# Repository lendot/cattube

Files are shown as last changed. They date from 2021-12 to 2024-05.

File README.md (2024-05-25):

# CatTube
### On-demand Video Entertainment For Cats

## 1. Intro
Cat walks up to screen, videos start playing. Cat walks away from screen,
videos stop playing. That's the gist of CatTube. A Raspberry Pi with an
ultrasonic distance sensor attached is given the CatTube software and
whatever videos a particular cat likes to watch, and when the sensor
detects they're within range, the videos will start playing until they 
leave.

We've had this system running for about 6 years in our living room and
two of our cats love it and use it multiple times a day. Not only that,
they grasped it intuitively right from the beginning and there really wasn't
any training required.

## 2. Hardware

- Raspberry Pi 3 or 4 (5 should work too, but I haven't tested yet)
- HDMI-capable monitor/TV
- US-100 ultrasonic sensor. These can be found at several electronics
supply places, including [Adafruit](https://www.adafruit.com/product/4019).
- Wires to connect the sensor to the Pi. F-F jumper wires are simplest.
If you 3D print the supplied enclosure design, 3" jumpers work best.

### 2.1. Hookup

Make the following connections between the US-100 and the Raspberry Pi:
| US-100 | Raspberry Pi |
| --- | --- |
| VCC | Pin 1 (+3V3) |
| Trig/Tx | Pin 8 (TXD0 UART, aka GPIO14) |
| Echo/Rx | Pin 10 (RXD0 UART, aka GPIO15) |
| GND (1) | Pin 6 (GND) |
| GND (2) | Pin 9 (GND) |

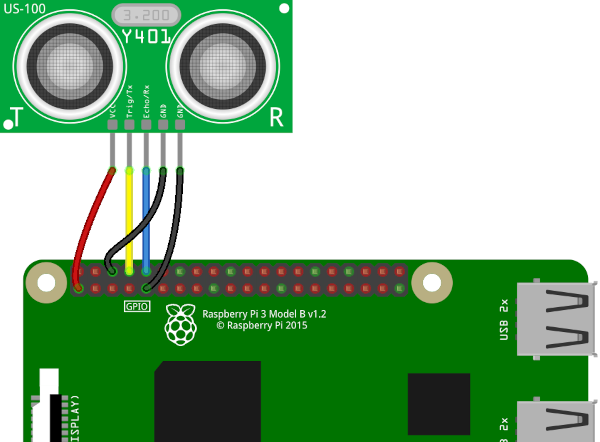
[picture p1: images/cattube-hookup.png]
wiring connections between Raspberry Pi and US-100


I haven't gotten around to investigating why this sensor breaks out 2
grounds. There's continuity between them so one could probably get away
with hooking up just one, but I do both just to be on the safe side.

## 3. Enclosure and Sensor Positioning

At minimum, you'll need some way to hold the sensor in place somewhere
at cat-level. If you have access to a 3D printer, .stl files for a wall-mount
enclosure are included in [enclosure](enclosure).

Keep the immediate area around the sensor free of obstructions, both on the 
sides and above and below. If an item such as the bottom edge of a television,
the side of a shelf, or even the floor is too close to the sensor, that
can cause the video player to activate and remain on. 

One good setup that doesn't take up much space is to wall-mount a small
TV/monitor a few inches above the sensor (the bottom of ours is 3.5" above
the sensor). Then you just need to allocate a roughly 2' x 2' space in
front of that TV where your cats can watch their videos.

## 4. Software

### 4.1. Operating system

If not installed already, install [Raspberry Pi OS](https://www.raspberrypi.com/software/).
Use the default operating system option recommended for your hardware.

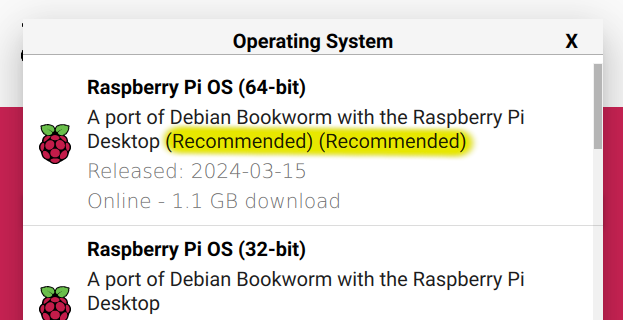
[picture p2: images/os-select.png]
Raspberry Pi OS installer Operating System dropdown sample highlighting the recommended option


NOTE: These instructions assume your Pi user is `pi`. If you set it to something else, you'll need to update all `/home/pi` references here and in `cattube.desktop` accordingly.

Make sure the Pi has internet access and has run its system updates before
continuing.

### 4.2. Python version

Open a terminal and run the following command to check your python version:
```
python --version
```
If the python version is 3.9.x or lower, proceed to the next section. If your
system comes with python 3.10 or higher you'll need to get a lower version 
installed first as one of the package dependencies doesn't yet support these newer
versions. One way to do this is by installing [pyenv](https://github.com/pyenv/pyenv) 
and using it to build and install python 3.9.x.

Here are the bare-bones commands for doing that after installing pyenv;
depending on your system you may need to install other system packages in order
to successfully build python.

These commands will install the python build dependencies, make sure tcl and tk
are installed so tkinter GUI support gets built in, and build and install the
specified python version. 3.9.18 is used here as that's the most recent 
python 3.9 release for pyenv as of this writing; see the pyenv documentation
for info on updating and listing available versions.

```sh
sudo apt install libbz2-dev libncurses-dev libffi-dev libreadline-dev liblzma-dev liblzma-dev liblzma-dev tcl tk tcl-dev tk-dev
pyenv install 3.9.18
```

### 4.3. Software install

Open a terminal and run the following commands to download CatTube and set up its run environment:
```sh
git clone https://github.com/lendot/cattube.git
cd cattube
# run the following command ONLY if you installed pyenv above
pyenv local 3.9.18
# run all the rest of these commands
python -m venv venv
source venv/bin/activate
pip install -r requirements.txt
cp cattube.desktop ../Desktop
```

Open File Manager and go to `Edit` > `Preferences` > `General` and check
"Don't ask options on launch executable file". You can then close that
window and exit File Manager.

From the desktop menu go to `Preferences` > `Raspberry Pi Configuration`
and do the following:
1. Go to the `Display` tab and disable `Screen Blanking`
2. Go to the `Interfaces` tab and enable `Serial Port`
3. If there is a `Serial Console` option, disable it

Click Ok and select Yes when asked to reboot.

### 4.4. Configuration
The configuration file is in `/home/pi/cattube/config.yaml`. It can be edited
with any text editor. The following settings can be tweaked there:

| Setting | Default | Description |
| --- | --- | --- |
| video_dir | /home/pi/Videos | Location of videos to play |
| distance | 50 | Maximum distance (cm) at which sensor will activate | 
| play_clips | False | If False, videos are played in their entirety. If True, random shorter subsections are played at a time |
| clip_duration| 180 | If play_clips is True, the length of clips (in seconds) to play |
| idle_timeout | 15 | How many seconds to keep playing the active video after the cat leaves before going back into standby, 0 = play out entire video/clip | 
| sensor_device| /dev/ttyS0 | If you need the sensor to to use a different serial device, set it here |

To help figure out the right distance setting to use in your configuration
file, or to determine if there are any obstacles interfering with a proper
distance reading, you can open up a terminal window and do the following:

```sh
cd ~/cattube
source venv/bin/activate
python sensor_readout.py
```

This will bring up a window that continuously updates a display of the
sensor's distance reading. As with the configuration file, values are in
centimeters.

play_clips is useful if you have longer videos and don't want the cats to get
bored watching them all the way through. Clip durations betwen about 120s and
300s seem to work well for our cats.

idle_timeout is also good for long videos as it can make video playing stop a
few seconds after a cat leaves rather than continuing dozens more minutes
(or longer).

### 4.5. Adding Videos

No videos are provided with CatTube. By default, it looks for videos in
`/home/pi/Videos`. Currently only mp4 videos are supported. See the Tips
For Videos section below for more information.

You can download videos from a browser or other application on the Pi desktop,
or you can use, say, sftp from another machine (assuming SSH is enabled on
the Pi). If you upload videos from another machine while CatTube is running,
it'll automatically add them to its video pool without requiring a restart.

### 4.6. Running CatTube

Once the hardware is hooked up and you have at least one video in your videos
directory, you can run CatTube. Double-click the CatTube icon on the
desktop to launch it. Simply clicking the left mouse button will exit the
program. Otherwise, no keyboard or mouse is required for the program to
function.

If you want CatTube to automatically start whenever the system boots up,
open a terminal window and run the following commands:
```sh
mkdir ~/.config/autostart
cd ~/cattube
cp cattube.desktop ~/.config/autostart
```

### 4.7. Troubleshooting

CatTube keeps a log file in `/home/pi/cattube/cattube.log`. Check that first
if anything's amiss.

## 5. Tips For Videos
We've found that the best videos are ones filmed from a single, stationary
camera. If the camera is moving, or the video is cutting between multiple
cameras, it gets more confusing for the cats to track. Youtube and other
places have a lot of good single camera little-critters-in-the-woods videos
and the like that our cats take really well to.

I recommend trying a bunch of different types of videos to see what your cat
responds to. In addition to the nature videos ours also like videos of
animated critters and things like balls rolling around. They're even sometimes
interested in gameplay videos from stuff like Tetris or Centipede. One of our
cats absolutely loves Line Rider videos. A while back I put an OK Go video
on ours just for laughs and months on our cats still really like watching
it. You never know what might grab their attention.

CatTube uses vlc to play the videos. The version that comes with
Raspberry Pi OS isn't compiled with hardware acceleration enabled, which limits
performance. A Pi 3 can handle standard 1K HD <= 30 FPS fine, but 4k or higher
frame rates give it trouble. Pi 4 is more forgiving. If a video is playing really
slowly, or is giving a black screen, you may need to decrease the resolution
and/or frame rate.

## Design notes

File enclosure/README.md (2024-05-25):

# Enclosure Files

Here are files for Pi 3 and 4 enclosures should you wish to 3D print
one. The ultrasonic sensor mounts on the underside of the cover through
the cat's eyes using the 2 standoffs and 2 M2x8 screws. The Pi mounts
to the body with 4 M2.5x8 screws. The body mounts to the wall via 2 #6
or #8 screws/anchors.

If you're having trouble getting the Pi in place, try rotating it into
position as shown here:

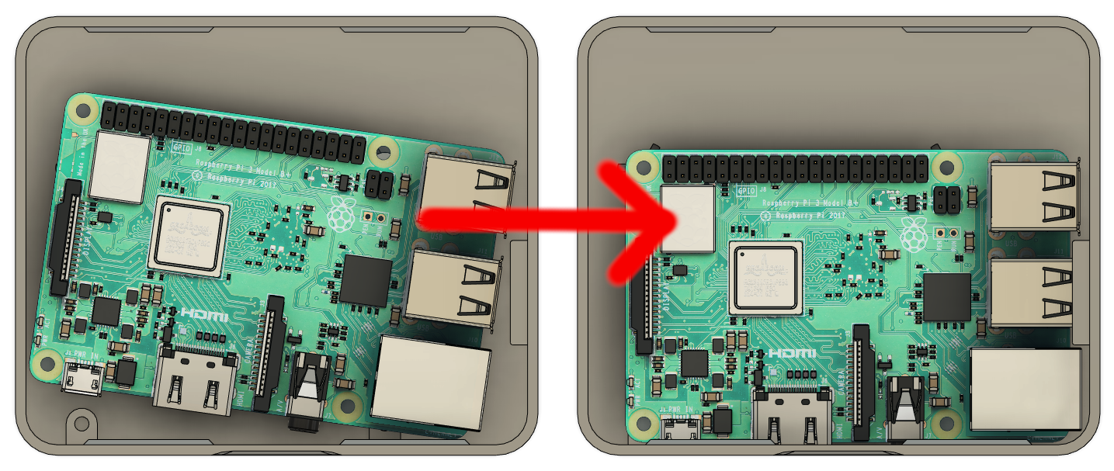
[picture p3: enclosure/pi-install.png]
installing Pi 3 in enclosure


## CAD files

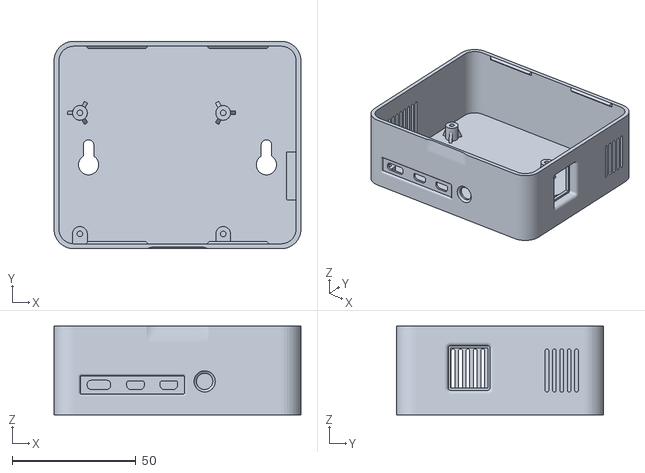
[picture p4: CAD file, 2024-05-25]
enclosure/body-pi4.stl
100.0 x 84.0 x 36.0

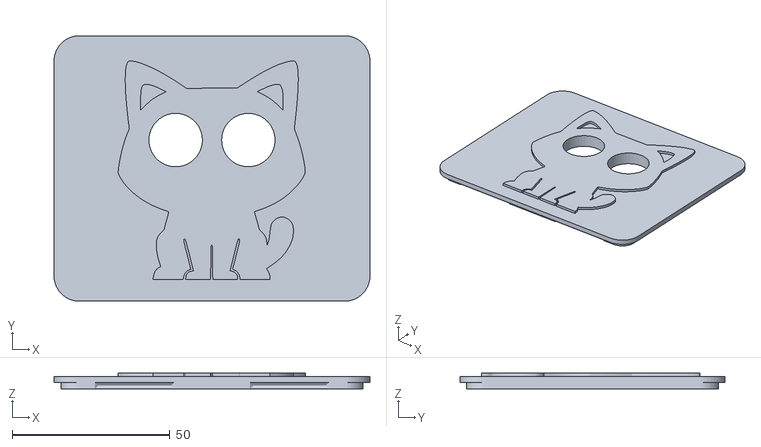
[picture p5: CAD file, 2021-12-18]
enclosure/cover.stl
100.0 x 84.0 x 5.00

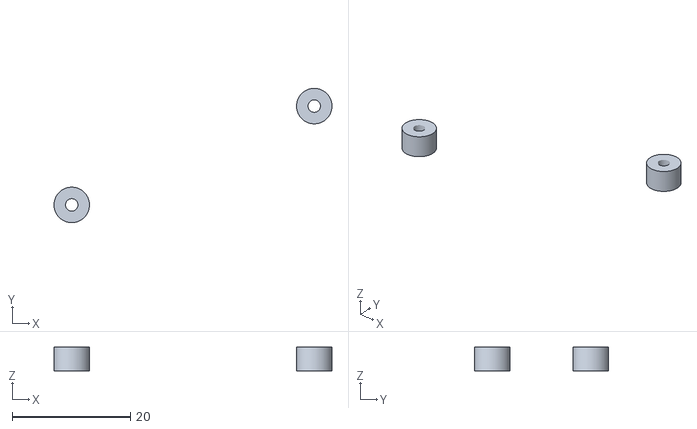
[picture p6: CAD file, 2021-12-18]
enclosure/standoffs.stl
47.0 x 22.7 x 4.00

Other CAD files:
enclosure/body-pi3.stl

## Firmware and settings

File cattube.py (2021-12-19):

import logging
import config
import videos
import distance_sensor
import tkinter as tk
import vlc
import random
import time

LOG_FILE = "cattube.log"

# number of seconds to wait after inactivity before stopping the running video
# 0 = don't time out 
DEFAULT_IDLE_TIMEOUT = 15

class View(tk.Frame):
    """ Top-level application frame """

    def __init__(self, parent, config, sensor, vids):
        super().__init__(parent)

        self.parent =parent 

        self.config = config
        self.sensor = sensor
        self.vids = vids

        self.video_playing = False
        self.video_end_timer = None
        self.idle = False

        self.play_clips = self.config.get("play_clips",False)
        logging.info ("play_clips: {}".format(self.play_clips))
        self.clip_duration = self.config.get("clip_duration",180)
        if self.play_clips:
            logging.info("clip_duration: {}".format(self.clip_duration))

        self.idle_timeout = self.config.get("idle_timeout",DEFAULT_IDLE_TIMEOUT)
        logging.info("idle_timeout: {}".format(self.idle_timeout))

        # make window full screen
        w,h = parent.winfo_screenwidth(), parent.winfo_screenheight()
        parent.geometry("{0}x{1}+0+0".format(w,h))
        # get rid of title bar, etc.
        parent.overrideredirect(1)
        parent.config(bg="black",cursor="none")

        self.video_frame = tk.Frame(parent,bg="black")
        self.video_frame.pack(expand=True,fill='both')

        # set up handlers for keypresses and mouse clicks
        parent.bind("<Key>",self.key_pressed)
        parent.bind("<Button>",self.mouse_click)


        # set up video player frame
        self.vlc_instance = vlc.Instance("--no-xlib")
        self.video_player = self.vlc_instance.media_player_new()
        self.video_player.set_xwindow(self.video_frame.winfo_id()) # attach vlc to this window

        self.update()


    def key_pressed(self,event):
        self.parent.destroy()

    def mouse_click(self,event):
        self.parent.destroy() 

    def update(self):
        """ update sensor status """
        active = self.sensor.update()
        if active:
            self.idle = False
            if self.video_playing:
                pass
            else:
                self.play_video()
        elif self.video_playing and self.idle_timeout > 0:
            if self.idle:
                now = time.monotonic()
                if now - self.idle_start > self.idle_timeout:
                    # kill the running video 
                    if self.video_end_timer is not None:
                        self.after_cancel(self.video_end_timer)
                    self.video_end()
            else:
                logging.info("Idle detected")
                self.idle_start = time.monotonic() 
                self.idle = True
            
        self.after(100,self.update)


    def video_end(self):
        """ time to make video stop """
        self.video_player.stop()
        logging.info("video ended")
        self.video_playing = False
        self.idle = False
        self.video_end_timer = None
        self.vlc_media.release()
        self.vlc_media = None

    def play_video(self):
        """ find a video to play and start playing it """
        video = self.vids.get_video()

        video_duration = int(video['duration'])

        # default: play entire video
        start = 0
        seek = 0
        duration = video_duration

        if self.play_clips and video_duration > self.clip_duration:
            # pick a random section of the video to play
            start = random.randint(0,video_duration-self.clip_duration)
            duration = self.clip_duration
            seek = start*1000 

        self.vlc_media = self.vlc_instance.media_new(video['filename'])
        self.video_player.set_media(self.vlc_media)

        logging.info("Playing video {} seek={}s duration={}s".format (video['filename'],start,duration))

        if self.video_player.play() == -1:
            logging.error("Can't play video")
            return

        # can't seek until after video starts playing
        self.video_player.set_time(seek)

        self.video_playing = True
        self.idle = False

        # set up callback to stop video play after duration
        self.video_end_timer = self.after(int(duration*1000),self.video_end)


class CatTube(tk.Tk):
    """ Main CatTube app class """
    def __init__(self):
        super().__init__()
        
        conf = config.CatTubeConfig()

        # set up the sensor
        kwargs = {}
        sensor_device = conf.get("sensor_device")
        if sensor_device is not None:
            kwargs['serial_device'] = sensor_device

        distance = conf.get("distance")
        if distance is not None:
            kwargs['distance'] = distance

        if len(kwargs) == 0:
            sensor = distance_sensor.DistanceSensor()
        else:
            sensor = distance_sensor.DistanceSensor(**kwargs)

        video_dir = conf.get("video_dir")
        if video_dir is None:
            vids = videos.Videos()
        else:
            vids = videos.Videos(video_dir = video_dir)

        # create view object(config,distance,video)
        view = View(self,conf,sensor,vids)


def main():

    logging.basicConfig(filename=LOG_FILE,
                        level=logging.INFO,
                        filemode="w",
                        format='%(asctime)s %(message)s')
    logging.info("cattube starting")
    
    app = CatTube()
    app.mainloop()

    logging.info("cattube exiting")


if __name__ == "__main__":
    try:
        main()
    except Exception as e:
        logging.exception("main exception")
    finally:
        logging.info("Exiting")

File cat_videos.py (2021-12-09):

import time
from os.path import join
import logging
import videos
import config
import distance_sensor
from watchdog.observers import Observer
from watchdog.events import PatternMatchingEventHandler

MURDERBOX_DIR = "/home/pi/src/murderboxws"

VIDEO_DIR = "/home/pi/videos"

LOG_FILE = "cat_videos.log"

# config file
CONFIG_FILE = "config.json"

# serial device to use to communicate with the US-100
SERIAL_DEVICE = "/dev/ttyS0"
sensor = distance_sensor.DistanceSensor(SERIAL_DEVICE)

# maximum distance to be considered near (cm)
near_threshold = 50
DEFAULT_NEAR_THRESHOLD = 50

# minimum distance to switch from near to away (cm)
away_threshold = 70


mute = False
play_clips = False

class ConfigChangeHandler(PatternMatchingEventHandler):
    # callback for when config file is changed

    def __init__(self, app, **kwargs):
        super().__init__(**kwargs)
        self.app = app

    def on_any_event(self, event):
        logging.info("Config file changed. Reloading")
        app.load_config()



class CatVideos:

    def __init__(self):
        self._init_logging()
        self.config = config.MurderboxConfig(CONFIG_FILE)
        self.load_config()
        self._setup_config_handler()
        self.near = False
        self.playing_video = False
        self.vids = videos.Videos(VIDEO_DIR)
        self.video = None
        
    def _init_logging(self):
        logging.basicConfig(filename=join(MURDERBOX_DIR,LOG_FILE),
                            filemode="w",
                            level=logging.INFO,
                            format='%(asctime)s %(message)s')
        logging.info("Murderbox starting")


        
    def _in_to_cm(self,inches):
        return inches * 2.54


    def _setup_config_handler(self):
        # set up handler for config file changes
        config_path = join(MURDERBOX_DIR,CONFIG_FILE)
        event_handler = ConfigChangeHandler(self,patterns=[config_path],ignore_patterns=[],ignore_directories=True)
        observer = Observer()
        observer.schedule(event_handler,MURDERBOX_DIR,recursive=False)
        observer.start()

    def load_config(self):
        # (re)load configuration
        
        self.config.load()
        
        self.near_threshold = self.config.get("distance",DEFAULT_NEAR_THRESHOLD)
        self.units = self.config.get("units","cm")
        if self.units != "cm":
            self.near_threshold = self._in_to_cm(self.near_threshold)
        self.away_threshold = self.near_threshold + 10

        logging.info ('near_threshold: {} cm'.format(self.near_threshold))
        logging.info ('away_threshold: {} cm'.format(self.away_threshold))

        self.mute = self.config.get("mute",False)
        logging.info ("mute: {}".format(mute))
            
        self.play_clips = self.config.get("play_clips",False)
        logging.info ("play_clips: {}".format(self.play_clips))
        
        self.clip_duration = self.config.get("clip_duration",180)
        if self.play_clips:
            logging.info("clip_duration: {}".format(self.clip_duration))

            
    def play(self):
        # play a video
        dur = 0
        if self.play_clips:
            dur = self.clip_duration
        self.video=self.vids.play_video(mute=self.mute,clip_duration=dur)
        if self.video is not None:
            self.playing_video = True

    def _update_video_playing(self):
        if self.vids.is_finished():
            logging.info("Video done")
            self.playing_video = False
        else:
            distance = sensor.get_distance()
            time.sleep(0.25)

    def _update_proximity_wait(self):
        distance = sensor.get_distance()
        if self.near:
            # we were last near; let's see we whether we still are
            if distance > self.away_threshold:
                self.near = False
                logging.info("Away (d={:.1f})".format(distance))
            else:
                logging.info("d={:.1f}".format(distance))
                self.play()
        elif distance < self.near_threshold:
            # we just moved from away to near
            logging.info("Near detected (d={:.1f}) Verifying.".format(distance))
            # do a few more readings to make sure it wasn't a blip
            self.near = True
            for i in range(3):
                dcheck=sensor.get_distance()
                logging.info("  d={:.1f}".format(dcheck))
                if dcheck >= self.near_threshold:
                    self.near = False
                    logging.info("abort")
                    break
                time.sleep(0.1)
            if self.near:
                logging.info("Verified. Playing video.")
                self.play()
        time.sleep(0.25)
            
            
    def update(self):
        # app update loop
        if self.playing_video:
            self._update_video_playing()
        else:
            self._update_proximity_wait()


app = CatVideos()

while True:
    app.update()

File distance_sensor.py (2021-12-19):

import serial
import logging
import time

# upper distance limit (cm)
MAX_DISTANCE = 200

# number of readings for the rolling average
NUM_READINGS = 5

# default serial device
SERIAL_DEVICE = "/dev/ttyS0"

DEFAULT_NEAR_THRESHOLD = 50

# maximum number of sensor read attempts before giving up
MAX_TRIES = 5


class DistanceSensor:
    """
    Read and process US_100 sensor distance readings
    """

    def __init__(self,
            serial_device = SERIAL_DEVICE,
            distance = DEFAULT_NEAR_THRESHOLD):
        self.serial_device = serial_device
        self.serial = serial.Serial(self.serial_device,timeout=5)
        self.readings = [MAX_DISTANCE] * NUM_READINGS
        self.readings_idx = 0
        self.near = False
        self.near_threshold = distance
        self.away_threshold = self.near_threshold + 10
        
    def _read_distance(self):
        """
        reads a raw distance from the US-100
        returns distance, in cm
        TODO: handle timeouts, etc.
        """

        self.serial.write(bytes([0x55]))
        success=False
        for attempt in range(MAX_TRIES):
            if attempt > 0:
                time.sleep(0.2)
                logging.error("retrying")

            # send command to read distance (0x55)
            self.serial.write(bytes([0x55]))
            data = self.serial.read(2)
            if len(data) < 2:
                # timeout occurred
                logging.error("Sensor read timeout.")
            else:
                success=True
                break

        if success:
            cm = (data[1] + (data[0] << 8)) / 10
            logging.debug("raw distance: {:.1f} cm".format(cm))
        else:
            logging.error("Giving up")
            # TODO do something better here
            cm = MAX_DISTANCE

        # cm = 30

        # sometimes readings go abnormally high (e.g. in the thousands)
        # there's probably a better way to handle this, but for now
        # we'll just clamp it to a reasonable max value
        cm = min(cm,MAX_DISTANCE)
        logging.debug("clamped distance: {:.1f} cm".format(cm))

        return cm

    def get_distance(self):
        """
        Get a smoothed distance reading.
        
        Smoothing is done via a rolling average
        """

        self.readings[self.readings_idx] = self._read_distance()
        self.readings_idx = (self.readings_idx+1) % NUM_READINGS

        readings_sum  = sum(self.readings)

        avg = readings_sum / NUM_READINGS
        
        logging.debug("smoothed distance: {:.1f} cm".format(avg))
        
        return avg

    def update(self):
        """
        Update sensor state

        Returns:
        bool: True if something is detected in front of the sensor 
        """
        distance = self.get_distance()
        if self.near:
            # we were last near; let's see we whether we still are
            if distance > self.away_threshold:
                self.near = False
                logging.info("Away (d={:.1f})".format(distance))
            else:
                logging.debug("d={:.1f}".format(distance))
        elif distance < self.near_threshold:
            # we just moved from away to near
            logging.info("Near detected (d={:.1f}) Verifying.".format(distance))
            # do a few more readings to make sure it wasn't a blip
            self.near = True
            for i in range(3):
                dcheck=self.get_distance()
                logging.info("  d={:.1f}".format(dcheck))
                if dcheck >= self.near_threshold:
                    self.near = False
                    logging.info("abort")
                    break
                time.sleep(0.05)
            if self.near:
                logging.info("Verified near.")

        return self.near

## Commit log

2021-02-15 switched print() calls to logging
2021-02-15 tightend up sleeps between sensor reads
    [cat_videos.py]
2021-02-20 overwrite log file on start, manual path construction replaced with os.join()
    [cat_videos.py]
2021-02-27 fixed max_reading calculation bug, clamped distance readings to MAX_DISTANCE
    [distance_sensor.py]
2021-10-20 prevented accidental activation by Schro's ghost
    [cat_videos.py]
2021-12-09 added stl files
    [base.stl, cover.stl]
2021-12-09 added enclosure README
2021-12-11 fixed wire rendering
2021-12-14 fixed path capitalization on VIDEO_DIR
    [videos.py]
2021-12-14 switched from tkVideoPlayer to using imageio
2021-12-14 switched logging filemode to w, logged video info
2021-12-15 switched to vlc
2021-12-15 set video frame background to black
2021-12-17 modified wiring instructions
2021-12-18 added new stls, removed old Pi Zero stuff
    [base.stl, body-pi3.stl, cover.stl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]
2021-12-18 sensor readout app
2021-12-19 fixed missing tkfont import
    [sensor_readout.py]
2021-12-19 fixed seek logging bug
    [cattube.py]
2021-12-19 added info on running sensor_readout
2021-12-19 fixed idle timeout bugs
    [cattube.py]
2021-12-19 added ventilation openings
    [body-pi3.stl]
2021-12-19 updated screw specs
2024-05-25 added Pi 4 enclosure stl
    [body-pi4.stl]
